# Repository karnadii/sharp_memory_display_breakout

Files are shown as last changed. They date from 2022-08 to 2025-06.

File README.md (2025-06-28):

# Sharp Memory Display Breakout (LS011B7DH03)

A breakout board for the Sharp LS011B7DH03, a 1.1-inch, 160x68 pixel monochrome memory display. This display is ideal for low-power applications like wireless keyboards due to its e-paper-like characteristics (~10µA power draw) and high refresh rate (30Hz).

This project is designed to be as small as possible, using fewer components than the Adafruit memory display breakout.

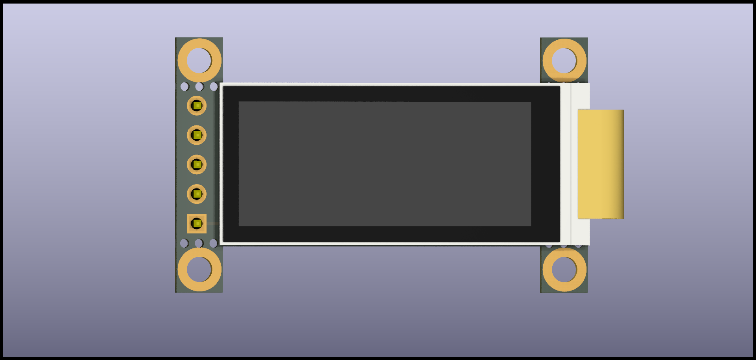
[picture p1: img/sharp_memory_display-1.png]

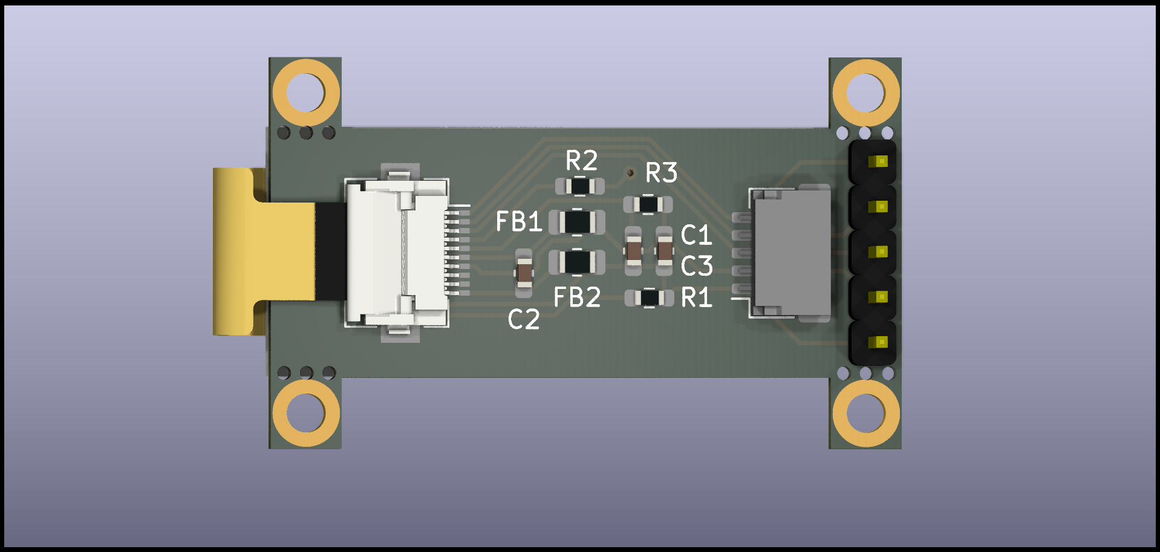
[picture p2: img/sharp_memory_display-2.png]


## Versions

This repository contains a few different versions of the breakout board. Production files (Gerber, schematic, STEP) for all versions are available in the [Releases section](https://github.com/karnadii/sharp_memory_display_breakout/releases).

### 1. Original Version (this branch)

This is the original design. It is designed with the pinout of a 128x32 OLED display in mind, making it a potential replacement for common displays used in mechanical keyboards.

### 2. nice!view Compatible Versions

To support the growing ecosystem around the [nice!view](https://nicekeyboards.com/nice-view), compatible versions of this breakout are available. These are intended as a DIY alternative if the nice!view is out of stock. They use the same pinout and should work with the same ZMK configurations.

- **[niceview-compat](https://github.com/karnadii/sharp_memory_display_breakout/tree/niceview-compat)**: Pin-compatible with mounting holes.
  

- **[niceview-compat-no-mount](https://github.com/karnadii/sharp_memory_display_breakout/tree/niceview-compat-no-mount)**: Pin-compatible without mounting holes for a smaller footprint.
  

> **Note:** This is a DIY project. For a ready-to-use product, consider purchasing the [nice!view](https://nicekeyboards.com/nice-view) instead.

## Design and Usage

### Pinout Compatibility

The original version is mostly pin-compatible with standard 128x32 I2C OLED displays used in many split keyboards. To replace an OLED, you may need to connect the `CLK` pin to a free GPIO on your microcontroller.



### Installation

The breakout can be used in several ways:
- **Socketed/Soldered:** Solder pin headers to use it directly with a microcontroller board.
- **Daughterboard:** Solder the JST connector and use it as a daughterboard. The mounting holes can be used for this purpose.

If you need a smaller board, the mounting hole tabs can be carefully broken off.

### PCB Size

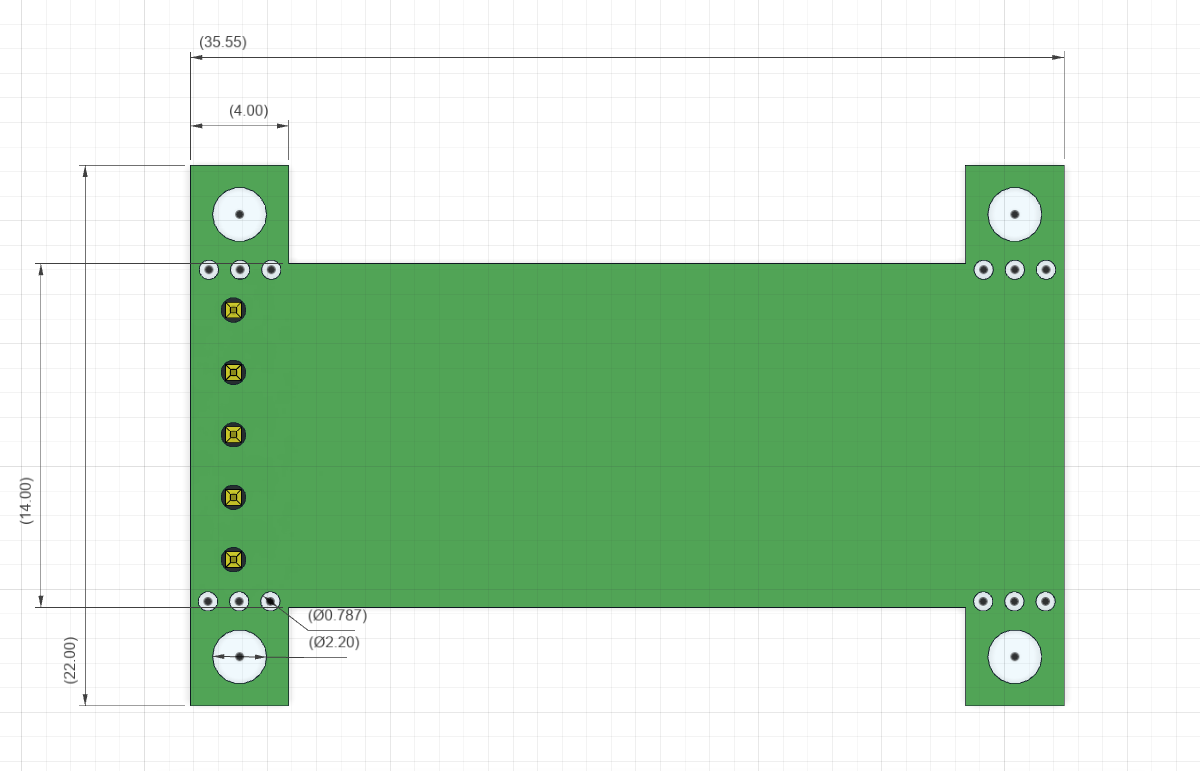
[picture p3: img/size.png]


## Bill of Materials (BOM)

| Ref | Qty | Value | Footprint | LCSC Part # | Notes |
|:--- |:---:|:---|:---|:---|:---|
| C1 | 1 | 560pF or 680pF | 0603 | C84721 | Unpolarized Capacitor |
| C2,C3 | 2 | 1uF | 0603 | C15849 | Unpolarized Capacitor |
| FB1,FB2 | 2 | Ferrite Bead | 0805 | C1017 | |
| J2 | 1 | FH12-10S-0.5SH | - | C506791 | FPC Connector |
| J3 | 1 | JST SH 5x1 | - | [AliExpress](https://www.aliexpress.com/item/1005003131441676.html) | Optional |
| R1,R2,R3 | 3 | 10kΩ | 0603 | C25804 | Optional |
| Display | 1 | LS011B7DH03 | - | [AliExpress](https://aliexpress.com/item/1005001809102193.html) | |

**Notes:**
- The resistors (R1, R2, R3) are optional and may not be required for the display to function.
- The LS011B7DH03 display can be difficult to source. The link provided is one of the few known sellers on AliExpress. Quality may vary.

## Cost Estimate

This is a DIY project. The approximate cost for a single breakout board is **$15 - $20** (before shipping), assuming you order 5 PCBs from a service like JLCPCB and source the displays from AliExpress. Costs can be reduced by sourcing components from cheaper vendors and self-assembly.

For comparison, the pre-built [nice!view](https://nicekeyboards.com/nice-view) is sold for around $20.

## Demos

The breakout has been tested with CircuitPython, Arduino, and ZMK (on an nrfmicro). Example code can be found in the `test_code` folder.

### Arduino
https://user-images.githubusercontent.com/18657277/137644641-276d998f-445c-41ad-aaf1-b85f445b7fb1.mp4

### CircuitPython
https://user-images.githubusercontent.com/18657277/146429499-8556456f-ffeb-47a3-a99c-73e11da73714.mp4

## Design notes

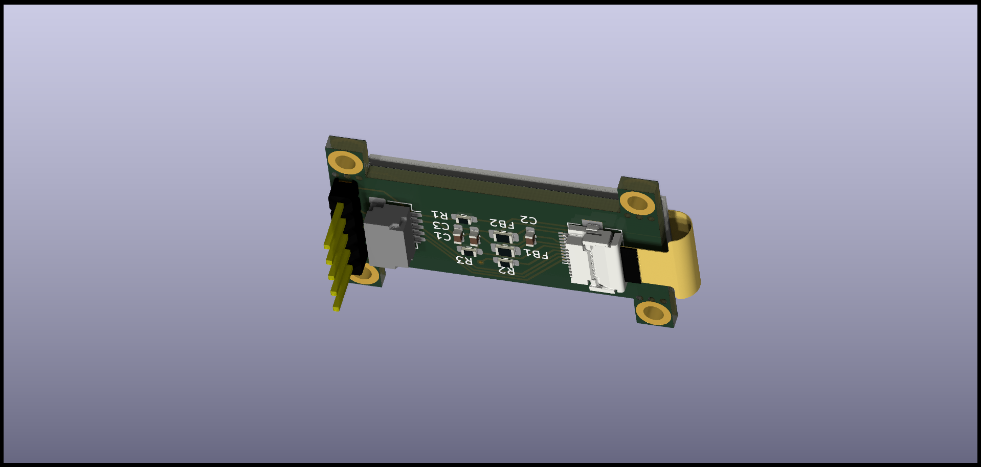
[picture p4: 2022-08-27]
img/sharp_memory_display-3.png

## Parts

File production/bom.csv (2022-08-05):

Comment | Designator | Footprint | LCSC Part #
560pF/680pF Unpolarized capacitor, small symbol | C1 | C_0603_1608Metric_Pad1.08x0.95mm_HandSolder | C84721
1uF Unpolarized capacitor, small symbol | C2 | C_0603_1608Metric_Pad1.08x0.95mm_HandSolder | C15849
1uF Unpolarized capacitor, small symbol | C3 | C_0603_1608Metric_Pad1.08x0.95mm_HandSolder | C15849
Ferrite_Bead_Small | FB1,FB2 | R_0805_2012Metric_Pad1.20x1.40mm_HandSolder | C1017
MountingHole Mounting Hole without connection | H1,H2,H3,H4 | MountingHole_2.2mm_M2_DIN965_Pad
Conn_01x05 Generic connector, single row, 01x05, script generated (kicad-library-utils/schlib/autogen/connector/) | J1 | PinSocket_1x05_P2.54mm_Vertical
Conn_01x10 Generic connector, single row, 01x10, script generated (kicad-library-utils/schlib/autogen/connector/) | J2,J4 | Hirose_FH12-10S-0.5SH_1x10-1MP_P0.50mm_Horizontal | C506791
Conn_01x05_Male Generic connector, single row, 01x05, script generated (kicad-library-utils/schlib/autogen/connector/) | J3 | JST_SH_SM05B-SRSS-TB_1x05-1MP_P1.00mm_Horizontal
10k Resistor, small symbol | R1,R2,R3 | R_0603_1608Metric_Pad0.98x0.95mm_HandSolder | C25804

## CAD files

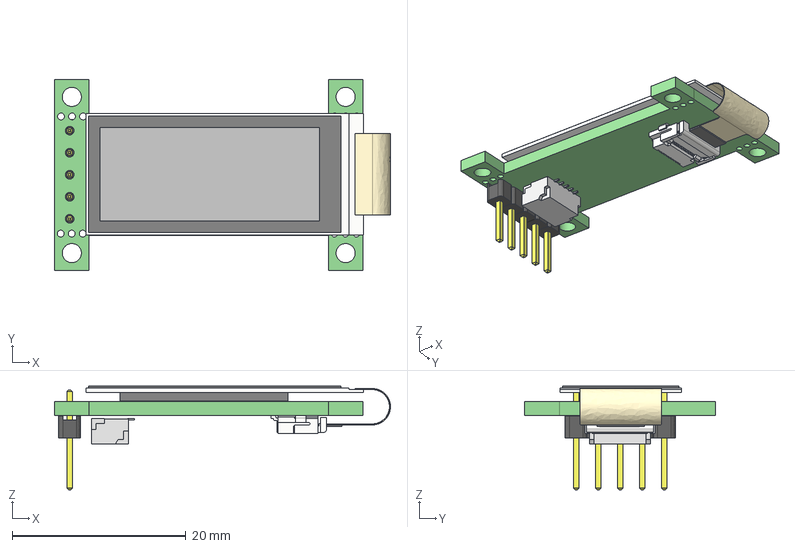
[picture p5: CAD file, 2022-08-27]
sharp_memory_display.step
38.7 x 22.0 x 12.0 mm
sharp_memory_display PCB

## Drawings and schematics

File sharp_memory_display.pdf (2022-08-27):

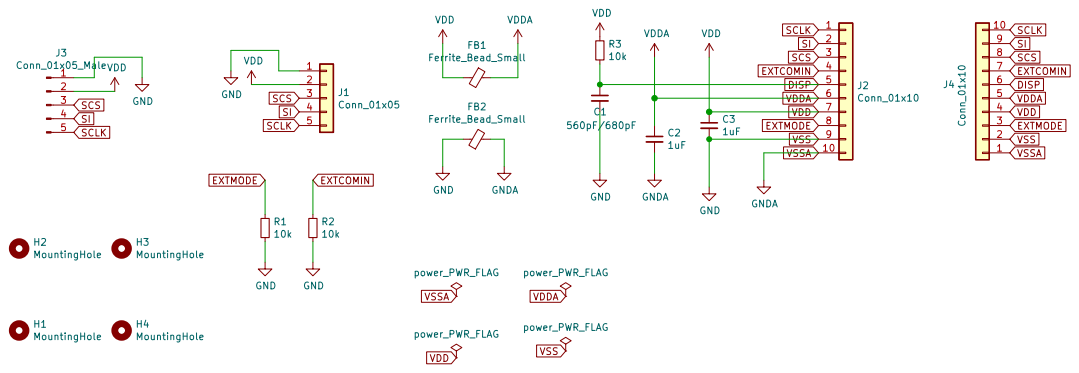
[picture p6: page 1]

6 VDDA

LS011B7DH03 Sharp memory display breakout

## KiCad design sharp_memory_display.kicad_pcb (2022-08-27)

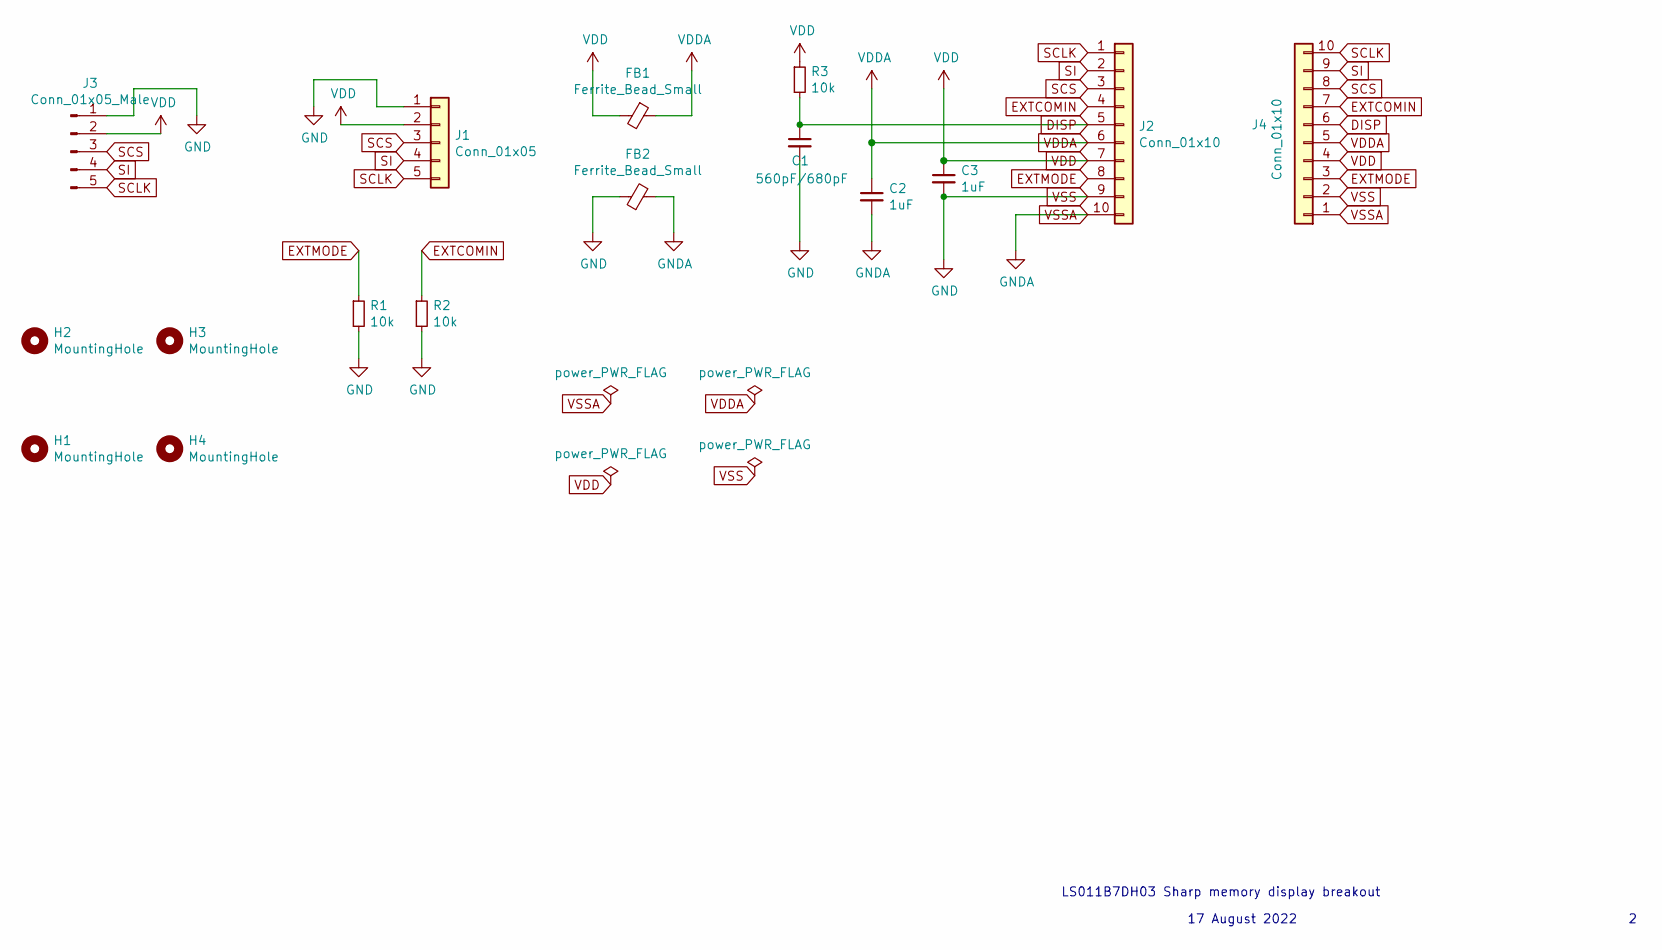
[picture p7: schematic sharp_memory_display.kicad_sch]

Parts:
C1: 560pF/680pF; C_0603_1608Metric_Pad1.08x0.95mm_HandSolder; LCSC C84721
C2, C3: 1uF; C_0603_1608Metric_Pad1.08x0.95mm_HandSolder; LCSC C15849
FB1, FB2: Ferrite_Bead_Small; R_0805_2012Metric_Pad1.20x1.40mm_HandSolder; LCSC C1017
H1, H2, H3, H4: MountingHole; MountingHole_2.2mm_M2_DIN965_Pad
J1: Conn_01x05; PinSocket_1x05_P2.54mm_Vertical
J2, J4: Conn_01x10; Hirose_FH12-10S-0.5SH_1x10-1MP_P0.50mm_Horizontal; LCSC C506791
J3: Conn_01x05_Male; JST_SH_SM05B-SRSS-TB_1x05-1MP_P1.00mm_Horizontal
R1, R2, R3: 10k; R_0603_1608Metric_Pad0.98x0.95mm_HandSolder; LCSC C25804

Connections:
DISP: C1.1, J2.5, J4.6, R3.2
EXTCOMIN: J2.4, J4.7, R2.1
EXTMODE: J2.8, J4.3, R1.1
SCLK: J1.5, J2.1, J3.5, J4.10
SCS: J1.3, J2.3, J3.3, J4.8
SI: J1.4, J2.2, J3.4, J4.9
VDD: C3.1, FB1.2, J1.2, J2.7, J3.2, J4.4, R3.1
VDDA: C2.1, FB1.1, J2.6, J4.5
VSS: C1.2, C3.2, FB2.1, J1.1, J2.9, J3.1, J4.2, R1.2, R2.2
VSSA: C2.2, FB2.2, J2.10, J4.1

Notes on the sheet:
17 August 2022
LS011B7DH03 Sharp memory display breakout

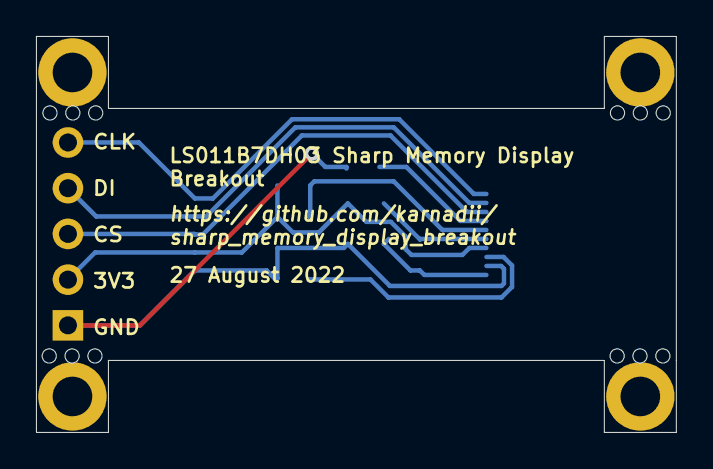
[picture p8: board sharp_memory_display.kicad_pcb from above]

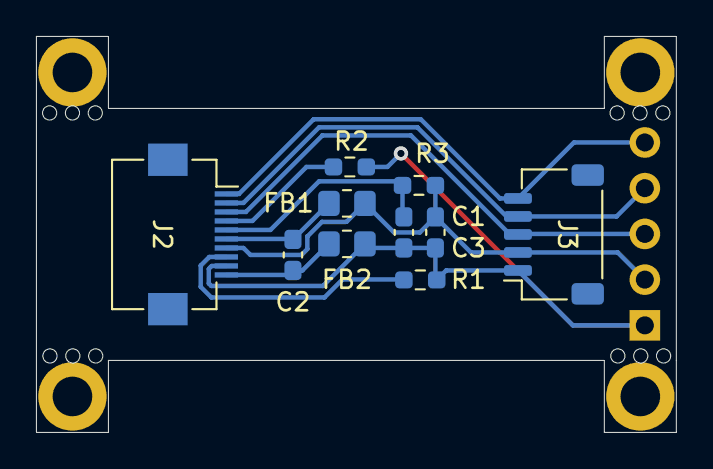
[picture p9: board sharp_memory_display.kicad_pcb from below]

Board: 2 copper layers, 35.5 x 22.0 mm, 15 parts (10 on the bottom side), 10 nets.

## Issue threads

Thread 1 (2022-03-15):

DISP connected to VDD?

Percentnineteen, 2022-03-15:
Hi, I was reviewing the documentation and was wondering why the connection up to VDD was omitted for the DISP pin? Was this an oversight?

karnadii, 2022-03-15:
are you reading the correct datasheet? DISP pin should not be connected to VDD at all

karnadii, 2022-03-15:
make sure you have the correct datahseet https://www.sharpsde.com/products/displays/model/ls011b7dh03/

Percentnineteen, 2022-03-16:
The datasheet says DISP is the on/off control for the display and has this note:
The display ON/OFF signal is only for display.
Data in the memory will be saved at the time of ON/OFF.
When it’s “Hi”, data in the memory will display, when it’s “Lo”, white color will display and
data in the memory will be saved.

The Adafruit implementation has the signal tied to a generated 3.3v (not VDD) through a 10k resistor (so the display is permanently on).

I guess what I'm asking is that I don't see any path to "Hi" in the schematic. It's possible I'm still reading something wrong, though.

karnadii, 2022-03-16:
I think either way will work. since I have tested the schematic. but I have updated the file with 10k pull up resistor to address your concern.

karnadii, 2022-08-05:
@Percentnineteen you are right, the connection between VDD and DISP is important. I have ordered and soldered my last revision with the 10k pull up resistor. It works, when removing the pull up resistor it is not working. it is weird the first design work without problem. Thanks for pointing it out and make an issue.

Percentnineteen, 2022-10-11:
The datasheet says DISP is the on/off control for the display and has this
note:
The display ON/OFF signal is only for display.
Data in the memory will be saved at the time of ON/OFF.
When it’s “Hi”, data in the memory will display, when it’s “Lo”, white
color will display and
data in the memory will be saved.

The Adafruit implementation has the signal tied to 3.3v (not VDD) through a
10k resistor (so the display is permanently on).

I guess what I'm asking is that I don't see any path to "Hi" in the
schematic. It's possible I'm still reading something wrong, though.

On Tue, Mar 15, 2022, 4:44 AM Ujang Karnadi ***@***.***>
wrote:

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

karnadii, 2022-10-11:
> Hi, I was reviewing the documentation and was wondering why the connection up to VDD was omitted for the DISP pin? Was this an oversight?

I just review your question again using google translate, so I just understand what you are asking. On the first release yeah I think I miss/forget the DISP pinout, Since I am not using the DISP pinout I should connect it to VDD so the display is always high, as you point it out then I added a pull up resistor connected to DISP to address your concern. To answer your question it is my fault not seeing that.

since we want the fewer pinout usage for GPIO, we are not using the DISP pinout, so DISP is connected to VDD/3.3v (in the latest update) to make it always on. So do you have another issue regarding the newest schematic? or another question? you are just repeating what you are saying previously.

since it is 3.3v only, it is doesn't matter if it is VDD or 3.3v that connected to DISP since VDD and 3.3v is connected.

Percentnineteen, 2022-10-11:
Sorry, not sure how or why that posted again...I suspect a GitHub issue somehow. I was asleep.

I agree with your previous fix to add the connection from DISP to VCC/3.3V

Closed 2022-03-16.

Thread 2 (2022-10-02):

Nice!view compatible pinout

karnadii, 2022-10-02:
since nice!view is released, and there will be a new board designed for nice!view in the future. I will make a version with compatible pinout of nice!view. so if in the future nice!view is Out of stock or some people find it expensive, my breakout can be an alternative. just like nrfmicro is an alternative to nice!nano. Also will reducing component just like nice!view schematic since nicell said the resistors isn't necessary.

karnadii, 2022-10-10:
updated with nice!view compatible pinout

Closed 2022-10-10.

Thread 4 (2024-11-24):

Evaluate possibility to use a different display module

AleCo3lho, 2024-11-24:
Hey @karnadii, do you think it is possible to create a board that uses this display instead, it is much cheaper and would be an interesting option. https://aliexpress.com/item/1005005883553891.html

I am interesting in learning how to create such a product, let me know if I can help with anything.

karnadii, 2024-11-24:
That is a different kind of display. You have to make a new pcb design. For e-paper refer to this repo by nicell https://github.com/Nicell/epaper-102
E-paper is energy efficient but not as fast as a sharp memory display though.

AleCo3lho, 2024-11-24:
Hey, thank you for the fast response, you are amazing.

I am from Brazil and the memory display ended up being to much expensive to import from nicell and to build it myself, even though e-paper is not good as memory display I think it is a good trade off in terms of energy efficiency.

karnadii, 2024-11-24:
In that case, you can build the e-paper by nicell I linked above. All the material is in the readme. Or you can re create the pcb to use different e-paper sizes. For the firmware I don't know if it is officially supported in ZMK but some keyboard like corneish zen use e-paper as well. You can look into their firmware if you decide to build one. But take note, it will need more pinout and most keyboard is not compatible, so you need to design your keyboard as well to support e-paper.

Closed 2024-11-24.

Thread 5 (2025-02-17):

Compatibility with other Sharp MIP

brandon-page, 2025-02-17:
Hello, is this PCB capable of driving [any of the other Sharp MIP displays](https://www.sharpsde.com/products/displays/memory-lcd/) or is it truly specific to the LS011B7DH03 model for some reason?

Thanks in advance!

karnadii, 2025-02-19:
It should be the same or almost identical, in fact the schematic initially just based on the [adafruit sharp memory display](https://www.adafruit.com/product/4694) which is larger than the LS011B7DH03. the only different probably just the size of the fpc pin connector. but if you want to try it on other display, make sure to check their datasheet first.

Closed 2025-02-19.

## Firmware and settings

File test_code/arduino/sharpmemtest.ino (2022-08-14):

/*********************************************************************
This is an example sketch for our Monochrome SHARP Memory Displays

  Pick one up today in the adafruit shop!
  ------> http://www.adafruit.com/products/1393

These displays use SPI to communicate, 3 pins are required to
interface

Adafruit invests time and resources providing this open source code,
please support Adafruit and open-source hardware by purchasing
products from Adafruit!

Written by Limor Fried/Ladyada  for Adafruit Industries.
BSD license, check license.txt for more information
All text above, must be included in any redistribution
*********************************************************************/

#include <Adafruit_GFX.h>
#include <Adafruit_SharpMem.h>

// Tested using nrfmicro edit your pin according to your controller

// any pins can be used
#define SHARP_SCK  45 //CLK P1_13
#define SHARP_MOSI 43 //DI P1_10
#define SHARP_SS   10//CS P0_10

// nrfmicro pin (32*pin)+gpio

// Set the size of the display here, e.g. 144x168!
Adafruit_SharpMem display(SHARP_SCK, SHARP_MOSI, SHARP_SS, 160, 68);
// The currently-available SHARP Memory Display (144x168 pixels)
// requires > 4K of microcontroller RAM; it WILL NOT WORK on Arduino Uno
// or other <4K "classic" devices!  The original display (96x96 pixels)
// does work there, but is no longer produced.

#define BLACK 0
#define WHITE 1

int minorHalfSize; // 1/2 of lesser of display width or height

void setup(void)
{
  Serial.begin(9600);
  Serial.println("Hello!");

  // start & clear the display
  display.begin();
  display.clearDisplay();

  // Several shapes are drawn centered on the screen.  Calculate 1/2 of
  // lesser of display width or height, this is used repeatedly later.
  minorHalfSize = min(display.width(), display.height()) / 2;

  // draw a single pixel
  display.drawPixel(10, 10, BLACK);
  display.refresh();
  delay(500);
  display.clearDisplay();

  // draw many lines
  testdrawline();
  delay(500);
  display.clearDisplay();

  // draw rectangles
  testdrawrect();
  delay(500);
  display.clearDisplay();

  // draw multiple rectangles
  testfillrect();
  display.refresh();
  delay(500);
  display.clearDisplay();

  // draw a circle, 10 pixel radius
  display.fillCircle(display.width()/2, display.height()/2, 10, BLACK);
  display.refresh();
  delay(500);
  display.clearDisplay();

  testdrawroundrect();
  display.refresh();
  delay(500);
  display.clearDisplay();

  testfillroundrect();
  display.refresh();
  delay(500);
  display.clearDisplay();

  testdrawtriangle();
  display.refresh();
  delay(500);
  display.clearDisplay();

  testfilltriangle();
  display.refresh();
  delay(500);
  display.clearDisplay();

  testdrawchar();
  display.refresh();
  for(int i=0; i<4; i++) {
    display.refresh();
    delay(500);
  }
}

void loop(void) 
{
  for(int i=0; i<4; i++) {
    display.setRotation(i);
    display.clearDisplay();
    // text display tests
    display.setTextSize(1);
    display.setTextColor(BLACK);
    display.setCursor(0,0);
    display.println("Hello, world!");
    display.setTextColor(WHITE, BLACK); // inverted text
    display.println(3.141592);
    display.setTextSize(2);
    display.setTextColor(BLACK);
    display.print("0x"); display.println(0xDEADBEEF, HEX);
    // Screen must be refreshed at least once per second
    for(int j=0; j<4; j++) {
      display.refresh();
      delay(500); // 1/2 sec delay
    } // x4 = 2 second pause between rotations
  }
}

///

void testdrawline() {
  for (int i=0; i<display.width(); i+=4) {
    display.drawLine(0, 0, i, display.height()-1, BLACK);
    display.refresh();
  }
  for (int i=0; i<display.height(); i+=4) {
    display.drawLine(0, 0, display.width()-1, i, BLACK);
    display.refresh();
  }
  delay(250);

  display.clearDisplay();
  for (int i=0; i<display.width(); i+=4) {
    display.drawLine(0, display.height()-1, i, 0, BLACK);
    display.refresh();
  }
  for (int i=display.height()-1; i>=0; i-=4) {
    display.drawLine(0, display.height()-1, display.width()-1, i, BLACK);
    display.refresh();
  }
  delay(250);

  display.clearDisplay();
  for (int i=display.width()-1; i>=0; i-=4) {
    display.drawLine(display.width()-1, display.height()-1, i, 0, BLACK);
    display.refresh();
  }
  for (int i=display.height()-1; i>=0; i-=4) {
    display.drawLine(display.width()-1, display.height()-1, 0, i, BLACK);
    display.refresh();
  }
  delay(250);

  display.clearDisplay();
  for (int i=0; i<display.height(); i+=4) {
    display.drawLine(display.width()-1, 0, 0, i, BLACK);
    display.refresh();
  }
  for (int i=0; i<display.width(); i+=4) {
    display.drawLine(display.width()-1, 0, i, display.height()-1, BLACK);
    display.refresh();
  }
  delay(250);
}

void testdrawrect(void) {
  for (int i=0; i<minorHalfSize; i+=2) {
    display.drawRect(i, i, display.width()-2*i, display.height()-2*i, BLACK);
    display.refresh();
  }
}

void testfillrect(void) {
  uint8_t color = BLACK;
  for (int i=0; i<minorHalfSize; i+=3) {
    // alternate colors
    display.fillRect(i, i, display.width()-i*2, display.height()-i*2, color&1);
    display.refresh();
    color++;
  }
}

void testdrawroundrect(void) {
  for (int i=0; i<minorHalfSize/2; i+=2) {
    display.drawRoundRect(i, i, display.width()-2*i, display.height()-2*i, minorHalfSize/2, BLACK);
    display.refresh();
  }
}

void testfillroundrect(void) {
  uint8_t color = BLACK;
  for (int i=0; i<minorHalfSize/2; i+=2) {
    display.fillRoundRect(i, i, display.width()-2*i, display.height()-2*i, minorHalfSize/2, color&1);
    display.refresh();
    color++;
  }
}

void testdrawtriangle(void) {
  for (int i=0; i<minorHalfSize; i+=5) {
    display.drawTriangle(display.width()/2, display.height()/2-i,
                     display.width()/2-i, display.height()/2+i,
                     display.width()/2+i, display.height()/2+i, BLACK);
    display.refresh();
  }
}

void testfilltriangle(void) {
  uint8_t color = BLACK;
  for (int i=minorHalfSize; i>0; i-=5) {
    display.fillTriangle(display.width()/2  , display.height()/2-i,
                         display.width()/2-i, display.height()/2+i,
                         display.width()/2+i, display.height()/2+i, color & 1);
    display.refresh();
    color++;
  }
}

void testdrawchar(void) {
  display.setTextSize(1);
  display.setTextColor(BLACK);
  display.setCursor(0,0);
  display.cp437(true);

  for (int i=0; i < 256; i++) {
    if (i == '\n') continue;
    display.write(i);
  }
  display.refresh();
}

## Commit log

2021-09-16 add solderable pad
    [sharp_memory_display-B_Cu.gbr, sharp_memory_display-B_Mask.gbr, sharp_memory_display-B_Paste.gbr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]
2022-03-16 add pullup resistor for DISP
    [sharp_memory_display.kicad_pcb, sharp_memory_display.kicad_sch]
2022-08-05 add new BOM and IBOM
    [bom.csv, designators.csv, positions.csv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]
2022-08-05 update readme and arduino code
2022-08-14 add test code for circuitpython
2022-08-17 tidy up schematic
    [sharp_memory_display.kicad_sch]
2022-08-27 add 3d files and update readme
    [designators.csv, positions.csv, sharp_memory_display.kicad_pcb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]
2025-06-28 docs: Remove ZMK line and ™ from README.md
